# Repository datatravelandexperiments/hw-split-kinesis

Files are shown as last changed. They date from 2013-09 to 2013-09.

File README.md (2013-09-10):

Split Keyboard
==============

This is the hardware for modifying a [Kinesis contoured keyboard](http://kinesis-ergo.com/contoured.htm) into two separated units.

**This is a work in progress, and the hardware/software described here has not been shown to work correctly.**

The replacement controller communicates by SPI to an I/O expander on each keywell. Each keywell board plugs in to the keywell using staggered pin headers replacing the original FFC connector, and has a separate connector for the thumb keys. The rubber function keys are abandoned; I intend to use a FN key on the thumb matrix instead.

The controller (kctlspi) uses a [Micropendous 32U2](http://code.google.com/p/micropendous/wiki/Micropendous_32U2) board, because I happened to have a few on hand. Modifying it to use a similar device like a Teeny, Pro Micro, etc. should be straightforward.

The controller board has two Mini-DIN 8 jacks for the keywells. The pinout of these connectors is chosen such that the controller board could be repurposed as a dual PS/2 converter by swapping in Mini-DIN 6 connectors.

The controller also has two 6p6c jacks. The middle 4 pins match the pinout of foot switches for current Kinesis contoured keyboards; the other two supply V<sub>CC</sub> and GND to allow the possibility of active devices. The foot connectors are wired as a 2×3 matrix.

The controller board is sized to fit (half) a [readily available project box](http://www.google.com/search?q=24+70+110+aluminum+project+box). (Note: Many 6p6c jacks are too tall to fit this enclosure.)

The keywell boards (lctlspi and rctlspi) each use an MCP23S17 I/O expander. An MCP23017 could be substituted directly to use I<sup>2</sup>C rather than SPI. The chip's <span style="text-decoration:overline">RESET</span> and <span style="text-decoration:overline">CS</span> pins are present on the connector, but can be pulled up/down on the board instead.

The appropriate INTx pin is also present on the connector, so it should be possible to set up the I/O expander and put the controller to sleep until any key is pressed.

Left and right keywell controllers are different because the Kinesis keywells have different matrices. The correspondence between keywell signals and I/O expander pins is arbitrary (i.e. determined by layout convenience); that is, column 1 on the keywell does not correspond to pin 1 on an I/O port, and so on. Similarly the thumb pad connectors have the same pattern (GND, four columns, three rows) but the specific arrangement of rows and columns is arbitrary.

Schematics and boards are in [Eagle CAD](http://www.cadsoftusa.com/download-eagle/) format.

<!-- vim:set et sts=4 sw=4 linebreak ft=ghmarkdown: -->

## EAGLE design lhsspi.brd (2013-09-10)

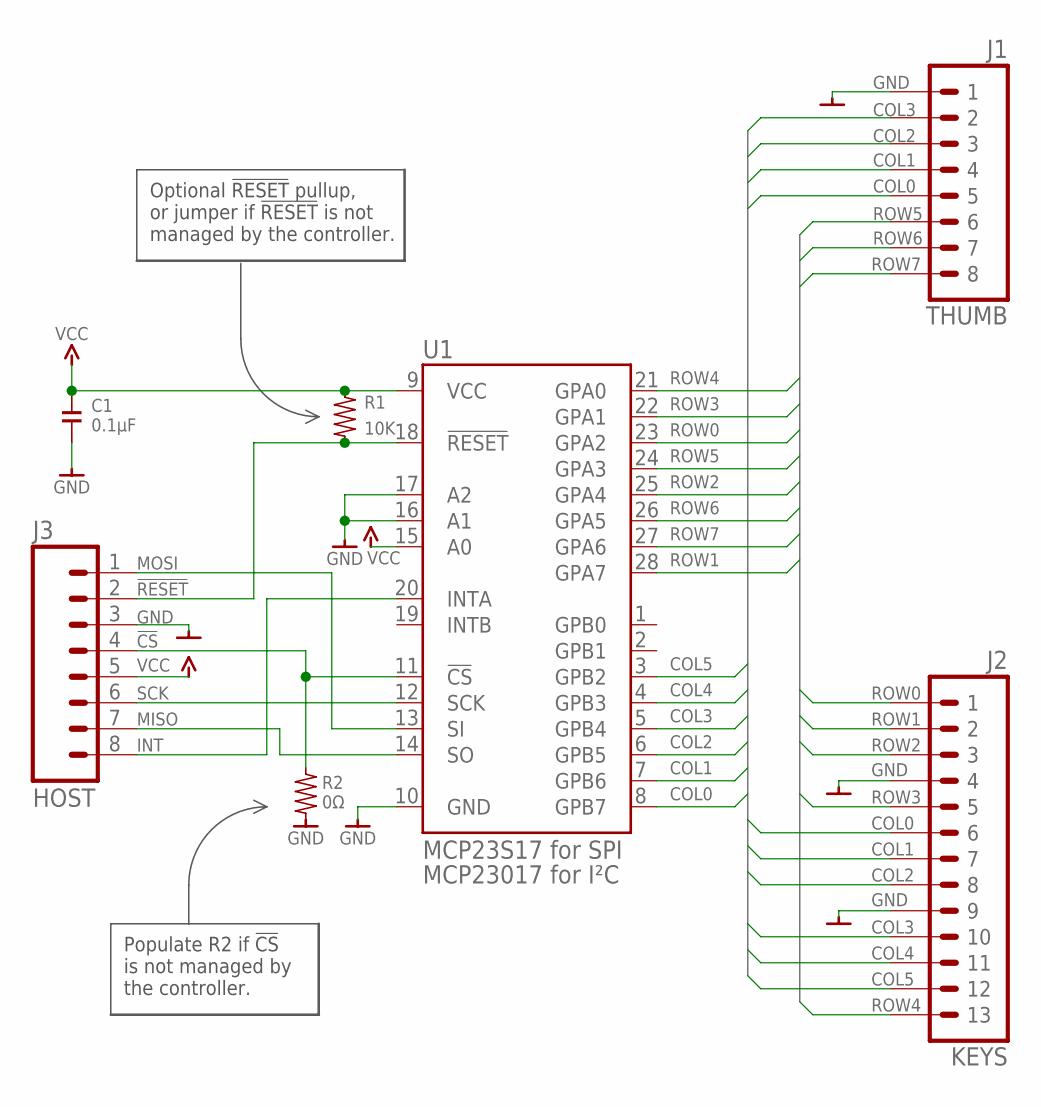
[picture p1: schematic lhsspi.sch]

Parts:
C1: 0.1µF; SMD-1206
J1: THUMB; J-8-2510
J2: KEYS; J-13-100-ALT-L
J3: HOST; J-8-2510
R1: 10K; SMD-1206
R2: 0Ω; SMD-1206
U1: MCP23S17 for SPI; IC-28-SOIC-300

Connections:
!CS: J3.4, R2.2, U1.11 (!CS)
!RESET: J3.2, R1.1, U1.18 (!RESET)
COL0: J1.5, J2.P6 (6), U1.8 (GPB7)
COL1: J1.4, J2.P7 (7), U1.7 (GPB6)
COL2: J1.3, J2.P8 (8), U1.6 (GPB5)
COL3: J1.2, J2.P10 (10), U1.5 (GPB4)
COL4: J2.P11 (11), U1.4 (GPB3)
COL5: J2.P12 (12), U1.3 (GPB2)
GND: C1.2, J1.1, J2.P4 (4), J2.P9 (9), J3.3, R2.1, U1.10 (GND), U1.16 (A1), U1.17 (A2)
INT: J3.8, U1.20 (INTA)
MISO: J3.7, U1.14 (SO)
MOSI: J3.1, U1.13 (SI)
ROW0: J2.P1 (1), U1.23 (GPA2)
ROW1: J2.P2 (2), U1.28 (GPA7)
ROW2: J2.P3 (3), U1.25 (GPA4)
ROW3: J2.P5 (5), U1.22 (GPA1)
ROW4: J2.P13 (13), U1.21 (GPA0)
ROW5: J1.6, U1.24 (GPA3)
ROW6: J1.7, U1.26 (GPA5)
ROW7: J1.8, U1.27 (GPA6)
SCK: J3.6, U1.12 (SCK)
VCC: C1.1, J3.5, R1.2, U1.9 (VCC), U1.15 (A0)

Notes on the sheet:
Populate R2 if !CS! is not managed by the controller.
MCP23017 for I²C
Optional !RESET! pullup, or jumper if !RESET! is not managed by the controller.

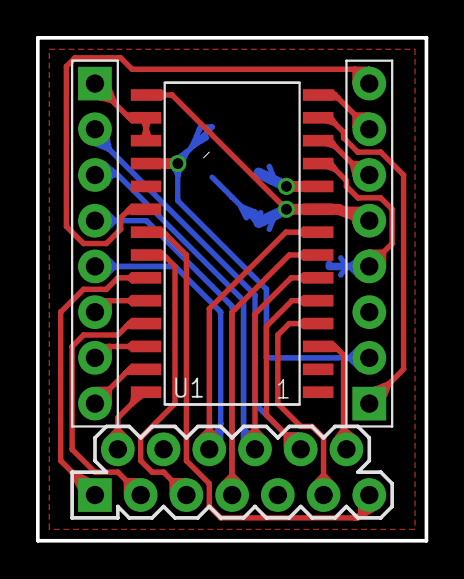
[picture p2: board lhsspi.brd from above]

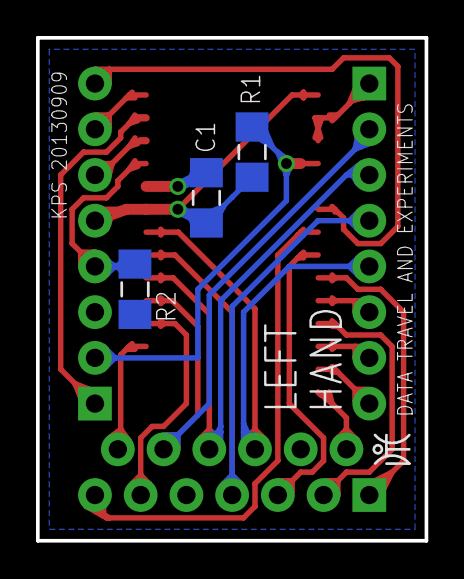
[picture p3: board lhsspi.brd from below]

Board: 2 copper layers, 21.6 x 27.9 mm, 7 parts (3 on the bottom side), 22 nets.

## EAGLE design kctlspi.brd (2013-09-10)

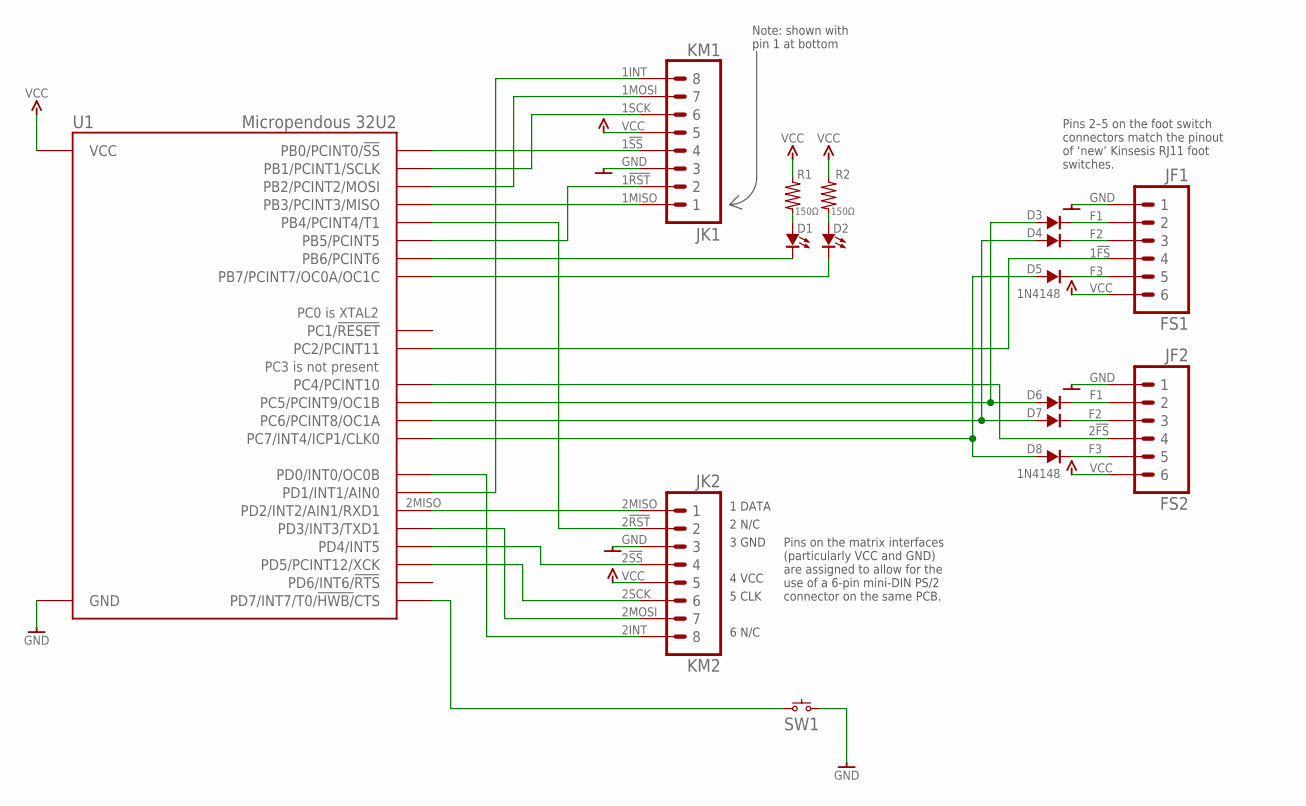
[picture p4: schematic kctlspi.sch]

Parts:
D1, D2: LED; 2H-100-P-EXTSS
D3, D4, D5, D6, D7, D8: 1N4148; 2H-300-P-SMALLSS
JF1: FS1; J-8-RJ12-TE5555163
JF2: FS2; J-8-RJ12-TE5555163
JK1: KM1; J-8-MINIDIN-KMD11
JK2: KM2; J-8-MINIDIN-KMD11
R1, R2: 150Ω; 2H-300-N-NOSS
SW1: SW-TACTILE-RA
U1: Micropendous 32U2; IC-ATMEGA32U2-NOOGROOVE

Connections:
1!FS: JF1.4, U1.PC2 (PC2/PCINT11)
1!RST: JK1.2, U1.PB5 (PB5/PCINT5)
1!SS: JK1.4, U1.PB0 (PB0/PCINT0/!SS)
1INT: JK1.8, U1.PD1 (PD1/INT1/AIN0)
1MISO: JK1.1, U1.PB3 (PB3/PCINT3/MISO)
1MOSI: JK1.7, U1.PB2 (PB2/PCINT2/MOSI)
1SCK: JK1.6, U1.PB1 (PB1/PCINT1/SCLK)
2!FS: JF2.4, U1.PC4 (PC4/PCINT10)
2!RST: JK2.2, U1.PB4 (PB4/PCINT4/T1)
2!SS: JK2.4, U1.PD4 (PD4/INT5)
2INT: JK2.8, U1.PD0 (PD0/INT0/OC0B)
2MISO: JK2.1, U1.PD2 (PD2/INT2/AIN1/RXD1)
2MOSI: JK2.7, U1.PD3 (PD3/INT3/TXD1)
2SCK: JK2.6, U1.PD5 (PD5/PCINT12/XCK)
F1: D3.A, D6.A, U1.PC5 (PC5/PCINT9/OC1B)
F2: D4.A, D7.A, U1.PC6 (PC6/PCINT8/OC1A)
F3: D5.A, D8.A, U1.PC7 (PC7/INT4/ICP1/CLK0)
GND: JF1.1, JF2.1, JK1.3, JK1.GND, JK2.3, JK2.GND, SW1.2, SW1.3 (GND), SW1.4 (GND), U1.GND
LED1: D1.C, U1.PB6 (PB6/PCINT6)
LED2: D2.C, U1.PB7 (PB7/PCINT7/OC0A/OC1C)
unnamed: SW1.1, U1.PD7 (PD7/INT7/T0/!HWB/!CTS)
unnamed: D3.C, JF1.2
unnamed: D4.C, JF1.3
unnamed: D5.C, JF1.5
unnamed: D8.C, JF2.5
unnamed: D7.C, JF2.3
unnamed: D6.C, JF2.2
unnamed: D2.A, R2.1
unnamed: D1.A, R1.1
VCC: JF1.6, JF2.6, JK1.5, JK2.5, R1.2, R2.2, U1.+5V (VCC)

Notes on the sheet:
1 DATA
2 N/C
3 GND
4 VCC
5 CLK
6 N/C
Pins on the matrix interfaces (particularly VCC and GND) are assigned to allow for the use of a 6-pin mini-DIN PS/2 connector on the same PCB.
Pins 2–5 on the foot switch connectors match the pinout of ‘new’ Kinsesis RJ11 foot switches.
Note: shown with pin 1 at bottom

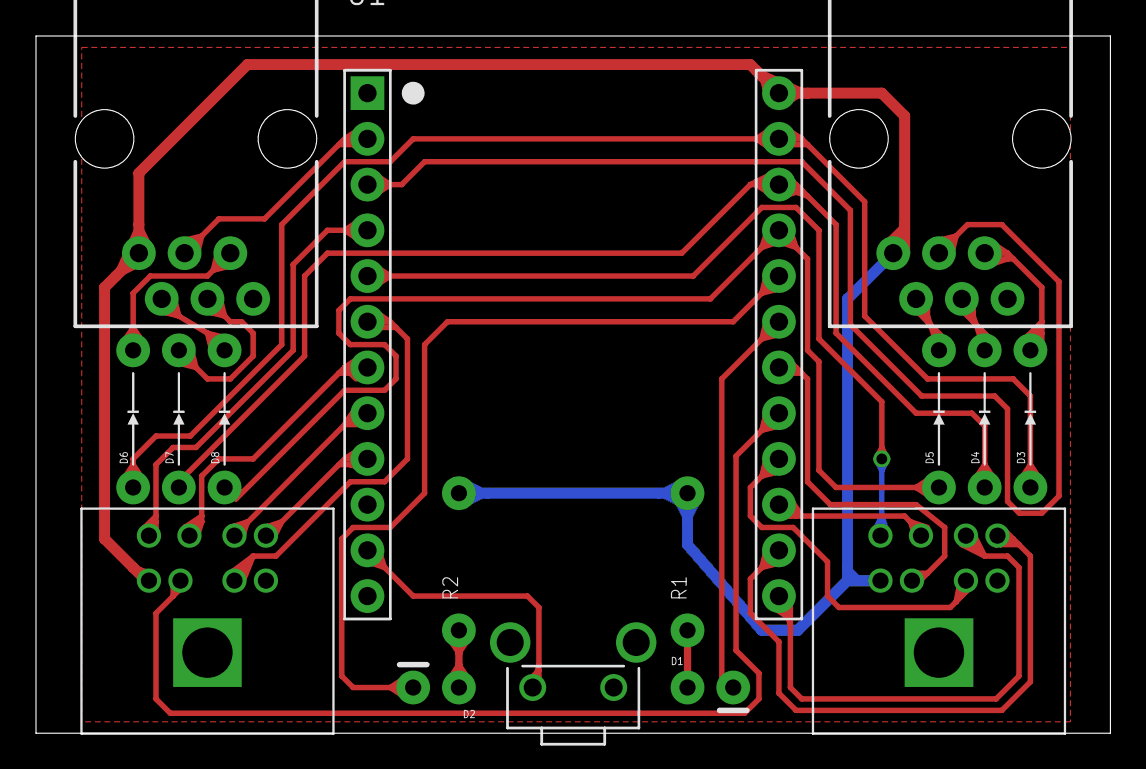
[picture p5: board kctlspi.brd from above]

Board: 2 copper layers, 59.7 x 38.7 mm, 17 parts (1 on the bottom side), 30 nets.

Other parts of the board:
U$2: GLYPH-DT&E-100

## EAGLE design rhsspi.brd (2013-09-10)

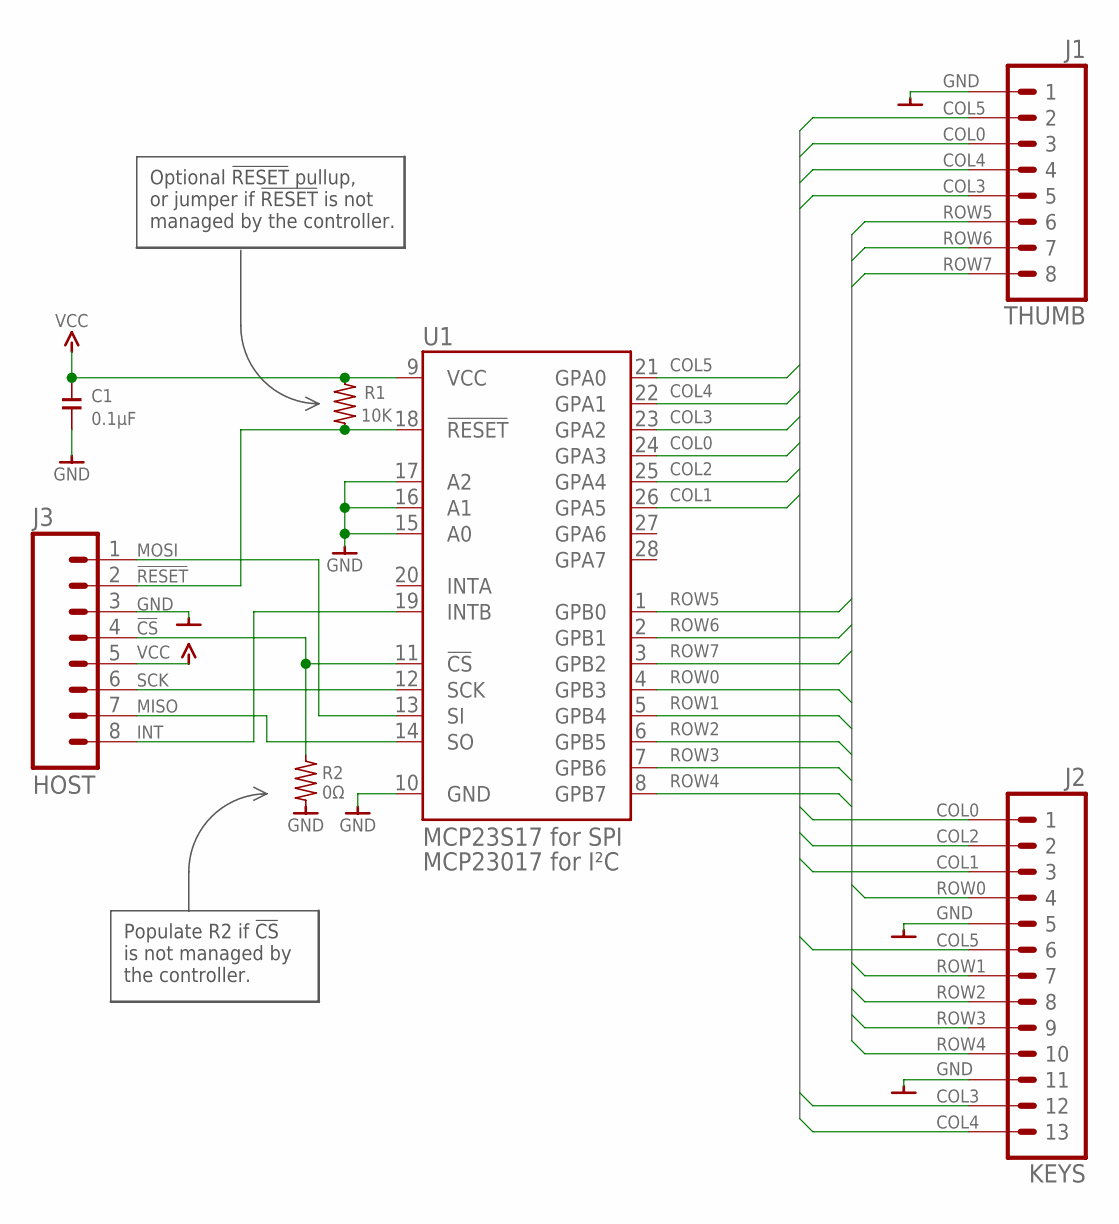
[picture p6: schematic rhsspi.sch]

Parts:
C1: 0.1µF; SMD-1206
J1: THUMB; J-8-2510
J2: KEYS; J-13-100-ALT-R
J3: HOST; J-8-2510
R1: 10K; SMD-1206
R2: 0Ω; SMD-1206
U1: MCP23S17 for SPI; IC-28-SOIC-300

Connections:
!CS: J3.4, R2.2, U1.11 (!CS)
!RESET: J3.2, R1.1, U1.18 (!RESET)
COL0: J1.3, J2.P1 (1), U1.24 (GPA3)
COL1: J2.P3 (3), U1.26 (GPA5)
COL2: J2.P2 (2), U1.25 (GPA4)
COL3: J1.5, J2.P12 (12), U1.23 (GPA2)
COL4: J1.4, J2.P13 (13), U1.22 (GPA1)
COL5: J1.2, J2.P6 (6), U1.21 (GPA0)
GND: C1.2, J1.1, J2.P5 (5), J2.P11 (11), J3.3, R2.1, U1.10 (GND), U1.15 (A0), U1.16 (A1), U1.17 (A2)
INT: J3.8, U1.19 (INTB)
MISO: J3.7, U1.14 (SO)
MOSI: J3.1, U1.13 (SI)
ROW0: J2.P4 (4), U1.4 (GPB3)
ROW1: J2.P7 (7), U1.5 (GPB4)
ROW2: J2.P8 (8), U1.6 (GPB5)
ROW3: J2.P9 (9), U1.7 (GPB6)
ROW4: J2.P10 (10), U1.8 (GPB7)
ROW5: J1.6, U1.1 (GPB0)
ROW6: J1.7, U1.2 (GPB1)
ROW7: J1.8, U1.3 (GPB2)
SCK: J3.6, U1.12 (SCK)
VCC: C1.1, J3.5, R1.2, U1.9 (VCC)

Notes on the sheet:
Populate R2 if !CS! is not managed by the controller.
Optional !RESET! pullup, or jumper if !RESET! is not managed by the controller.
MCP23017 for I²C

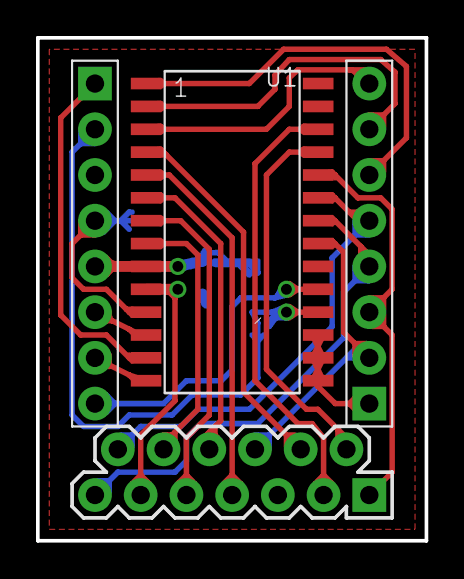
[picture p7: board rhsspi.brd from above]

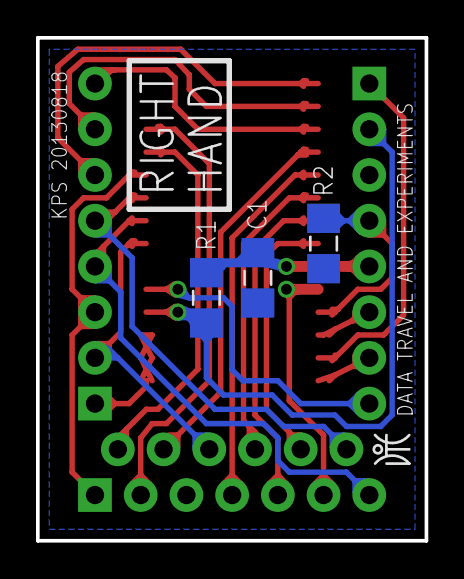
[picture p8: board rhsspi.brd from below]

Board: 2 copper layers, 21.6 x 27.9 mm, 7 parts (3 on the bottom side), 22 nets.

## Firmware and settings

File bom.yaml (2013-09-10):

name: Split Kinesis-based keyboard

parts:

  - &C-0-1UF-SMD-1206
    value:      0.1μF
    package:    SMD-1206
    source:
      - http://www.digikey.ca/product-detail/en/CL31B104KBCNNNC/1276-1017-1-ND/3889103

  - &C-1UF-SMD-1206
    value:      1μF
    package:    SMD-1206
    source:
      - http://www.digikey.ca/product-detail/en/CL31B105KOFNNNE/1276-1783-1-ND/3889869

  - &IC-MCP23S17-SOIC
    value:      MCP32S17
    package:    IC-28-SOIC-300
    desc:       16 bit I/O expander with SPI interface.
    source:
      - http://www.digikey.ca/product-detail/en/MCP23S17-E%2FSO/MCP23S17-E%2FSO-ND/894275

  - &IC-ATMEGA32U2-NOOGROOVE
    desc:       ATmega32U2 development board.
    source:
      - http://code.google.com/p/micropendous/wiki/Micropendous_32U2

  - &J-6-RJ12-LP
    desc:       6P6C RJ12 modular jack, low profile
    package:    J-8-RJ12-TE5555163
    source:
      - http://www.digikey.ca/product-detail/en/5555163-1/A31420-ND/769564

  - &J-8-2510-M
    desc:       8-pin right angle polarized header, 0.1″ spacing
    source:
      - http://futurlec.com/Connectors/POLHDRR8.shtml
      - http://www.ebay.ca/itm/230985641780

  - &J-8-SHIELD-MINIDIN
    desc:       8-pin mini-DIN female connector
    package:    J-8-MINIDIN-KMD11
    source:
      - http://www.ebay.ca/itm/140431326834

  - &J-13-100-ALT-F
    desc:       13-pin 0.1″ female header, two rows offset 0.05″

  - &J-13-100-ALT-M
    desc:       13-pin 0.1″ male header, two rows offset 0.05″

  - &LED-RED-5MM
    desc:       LED, 5mm round, red

  - &R-0-SMD-1206
    value:      0Ω
    package:    SMD-1206
    source:
      - http://www.digikey.ca/product-detail/en/RC3216J000CS/1276-3514-1-ND/3903617
      - http://www.digikey.ca/product-detail/en/RC1206JR-070RL/311-0.0ERCT-ND/732131

  - &R-150-025W
    value:      150Ω
    package:    ¼W axial

  - &R-10K-SMD-1206
    value:      10KΩ
    package:    SMD-1206
    source:
      - http://www.digikey.ca/product-detail/en/RC1206JR-0710KL/311-10KERCT-ND/732156

  - &SW-TACTILE-RA-MOM-NO
    desc:       tactile switch, momentary normally open, right angle
    package:    SW-TACTILE-RA
    source:
      - http://www.digikey.ca/product-detail/en/FSMRA7JH/450-1661-ND/1632547

boards:

  -
    name:         lhsspi
    description:  Left-hand SPI-controlled matrix controller.
    parts:
      &SPI-MATRIX-PARTS
      - {name: C1, part: *C-0-1UF-SMD-1206}
      - {name: J1, part: *J-8-2510-M}
      - {name: J2, part: *J-13-100-ALT-M}
      - {name: J3, part: *J-8-2510-M}
      - {name: R1, part: *R-10K-SMD-1206}
      - {name: R2, part: [null, *R-0-SMD-1206]}
      - {name: U1, part: *IC-MCP23S17-SOIC}

  -
    name:         rhsspi
    description:  Right-hand SPI-controlled matrix controller.
    parts:
      *SPI-MATRIX-PARTS

  -
    name:         nctl
    parts:
      - {name: D1,  part: *LED-RED-5MM}
      - {name: D2,  part: *LED-RED-5MM}
      - {name: JF1, part: *J-6-RJ12-LP}
      - {name: JF2, part: *J-6-RJ12-LP}
      - {name: JK1, part: *J-8-SHIELD-MINIDIN}
      - {name: JK2, part: *J-8-SHIELD-MINIDIN}
      - {name: R1,  part: *R-150-025W}
      - {name: R2,  part: *R-150-025W}
      - {name: SW1, part: *SW-TACTILE-RA-MOM-NO}
      - {name: U1,  part: *IC-ATMEGA32U2-NOOGROOVE}

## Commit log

2013-09-10 Fiat lux.
    [kctlspi.brd, kctlspi.sch, lhsspi.brd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]
2013-09-10 Move R1.
    [lhsspi.brd]
